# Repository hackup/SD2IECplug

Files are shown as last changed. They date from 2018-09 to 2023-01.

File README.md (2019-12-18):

SD2IEC Pluggable
================

* KiCAD project files for my take on a [SD2IEC](http://www.pitsch.de/stuff/mmc2iec/) compatible board.
* The schematics are heavily based on the [design by Shadowolf](https://www.forum64.de/index.php?thread/21242-sd2iec-hardware-1-0/).
* The [BOM export](SD2IECplug-BOM.csv) is included in the repository.
* There should probably be more documentation here, but while it is still missing you may find some additional information [on my blog](https://www.hackup.net/tag/sd2iec/).
* This is all work in progress with absolutely no guarantees. **USE AT YOUR OWN RISK!**

### Revision 2

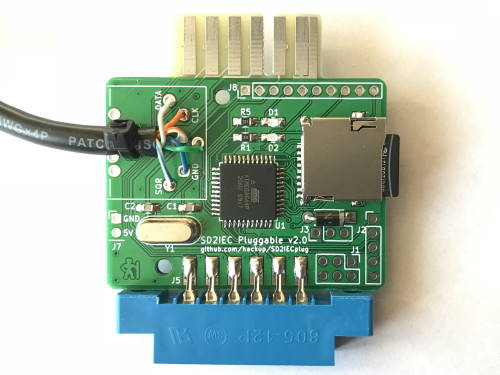
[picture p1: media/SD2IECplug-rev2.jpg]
SD2IECplug Rev.2


In revision 2, the PCB size has been reduced by more than 50% and TAPuino support has been ditched. It now features a Micro SD slot and a few other improvements. Note: In this revision, the numbering of the LEDs has been accidentally reversed. This has been fixed later on the master branch.

### Revision 1

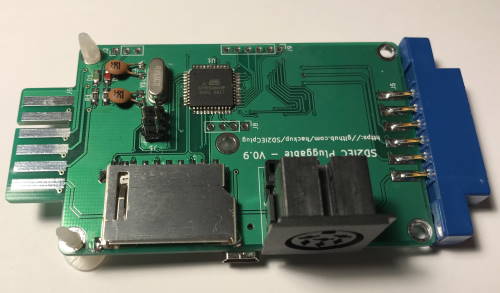
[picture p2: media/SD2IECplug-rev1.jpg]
SD2IECplug Rev.1


The first revision required a much larger PCB but featured a full-size SD slot and experimental support for TAPuino functionality. The latter was never tested though and probably wouldn't work.

If you don't intend to use the TAPuino functionality (and there isn't any firmware support for this yet) you can omit R16-R21 and the optocoupler U3. Also, the board can be power either through the USB or the tape port connector so you don't necessarily need to fit both.

## License


This work is licensed under a
[Creative Commons Attribution-NonCommercial-ShareAlike 4.0 International License](http://creativecommons.org/licenses/by-nc-sa/4.0/).

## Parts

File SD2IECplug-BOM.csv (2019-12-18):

Title | SD2IEC Pluggable
Revision | 2.1
Date | 2019-12-18
Generated | 18/12/2019 10:01:49
Company | www.hackup.net
Comment 1
Comment 2
Comment 3
Comment 4
Total Parts | 48
Total Unique Parts | 29
Ref | Qty | Value | Footprint | Datasheet | Manf | Manf#
C1 C2 | 2 | 56p | Capacitors_SMD:C_0805_HandSoldering
C3 C4 C5 | 3 | 10µ | Capacitors_Tantalum_SMD:CP_Tantalum_Case-S_EIA-3216-12_Hand
C6 | 1 | 100n | Capacitors_SMD:C_0805_HandSoldering
C7 | 1 | 100n | Capacitors_SMD:C_0805_HandSoldering | ~
D1 | 1 | red | LEDs:LED_0805_HandSoldering
D2 | 1 | green | LEDs:LED_0805_HandSoldering
D3 | 1 | 1N5817 | Diodes_THT:D_DO-41_SOD81_P7.62mm_Horizontal
J1 | 1 | ISP | Pin_Headers:Pin_Header_Straight_2x03_Pitch2.54mm
J2 | 1 | X6 | Pin_Headers:Pin_Header_Straight_1x05_Pitch2.54mm | ~
J3 | 1 | Aux | Pin_Headers:Pin_Header_Straight_1x03_Pitch2.54mm | ~
J4 | 1 | IEC | DIN-Connectors:DIN-6-Variable
J5 | 1 | C64-CassettePort | hackup:C64-Cassette-Port-Female
J6 | 1 | C64-CassettePort | hackup:C64-Cassette-Port-Male
J7 | 1 | Power | Pin_Headers:Pin_Header_Straight_1x02_Pitch2.54mm | ~
J8 | 1 | X3 | Pin_Headers:Pin_Header_Straight_1x10_Pitch2.54mm | ~
MH1 MH2 | 2 | ZipTie | DIN-Connectors:ZipTie_3.0mm | ~
MH3 MH4 | 2 | MountingHole | Mounting_Holes:MountingHole_2.7mm_M2.5 | ~
Q1 Q2 Q3 Q4 | 4 | BSS138 | TO_SOT_Packages_SMD:SOT-23_Handsoldering
R1 R5 | 2 | 330 | Resistors_SMD:R_0805_HandSoldering
R2 R6 R9 R12 | 4 | 18 | Resistors_SMD:R_0805_HandSoldering
R3 R7 R10 R13 | 4 | 10k | Resistors_SMD:R_0805_HandSoldering
R4 R8 R11 R14 | 4 | 22k | Resistors_SMD:R_0805_HandSoldering
R15 | 1 | 2.2R | Resistors_SMD:R_0805_HandSoldering
R16 | 1 | nB | Resistors_SMD:R_0805_HandSoldering | ~
SW1 SW2 | 2 | SW_Push | Buttons_Switches_SMD:SW_SPST_FSMSM
U1 | 1 | ATMEGA644-20AU | Housings_QFP:TQFP-44_10x10mm_Pitch0.8mm
U2 | 1 | AMS1117-3.3 | TO_SOT_Packages_SMD:SOT-223-3_TabPin2
XS1 | 1 | SD Connector | lib:Conn_uSDcard | _ | ebay | _
Y1 | 1 | 8MHz | Crystals:Crystal_HC49-4H_Vertical
BOM made with KICAD_BOM_WIZARD (https://github.com/HashDefineElectronics/KiCad_BOM_Wizard.git)
Generated 18/12/2019 10:01:49

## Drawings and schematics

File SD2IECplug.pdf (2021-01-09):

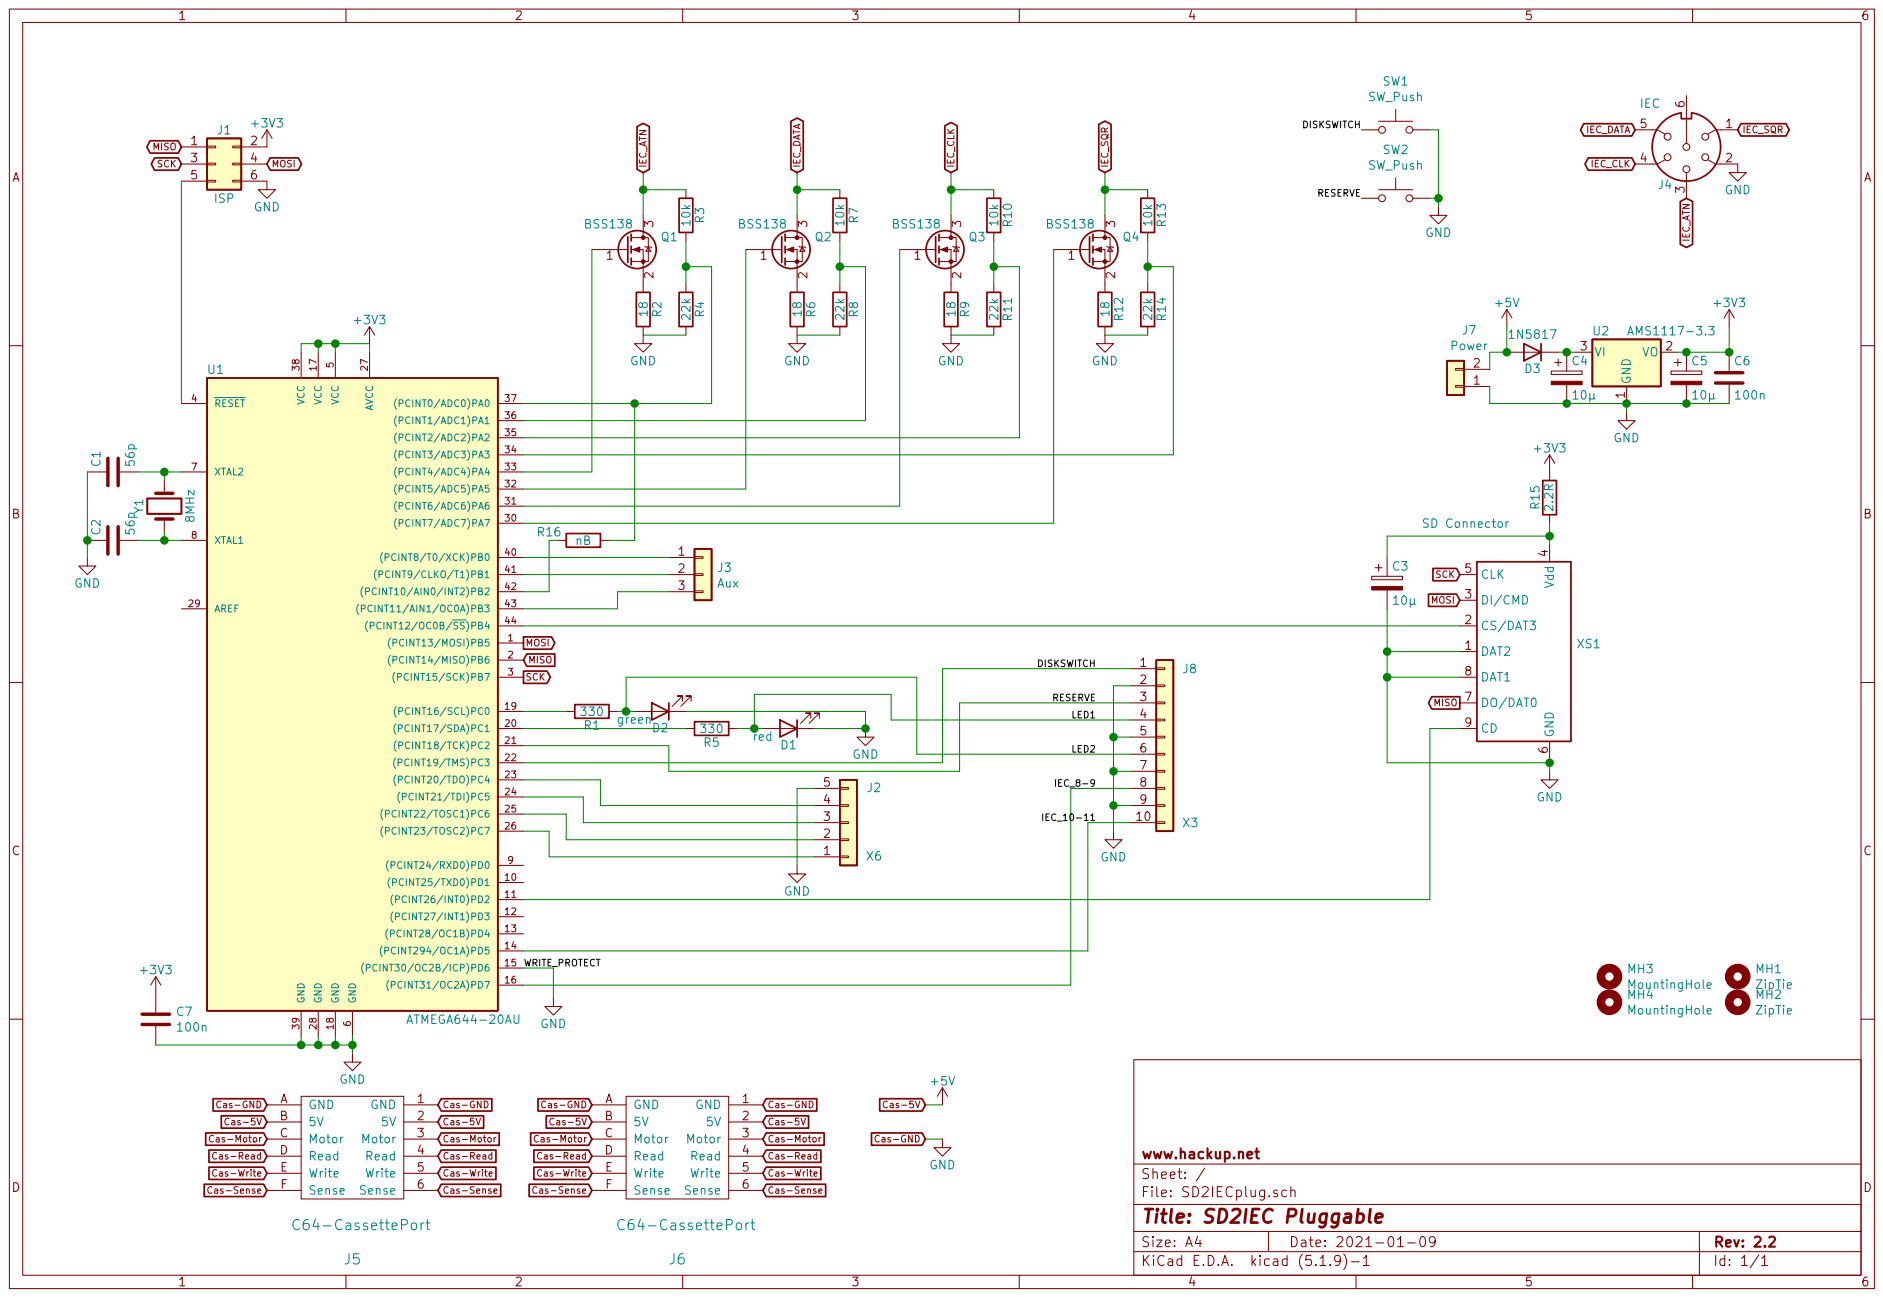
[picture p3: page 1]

6 DO/DAT0 7 DAT1 8 CD 9 XS1 SD Connector +5V GND GND MH1 ZipTie MH2 ZipTie GND

Cas-5V Cas-Motor MISO

LED2 | 5

File: SD2IECplug.sch Sheet: / www.hackup.net

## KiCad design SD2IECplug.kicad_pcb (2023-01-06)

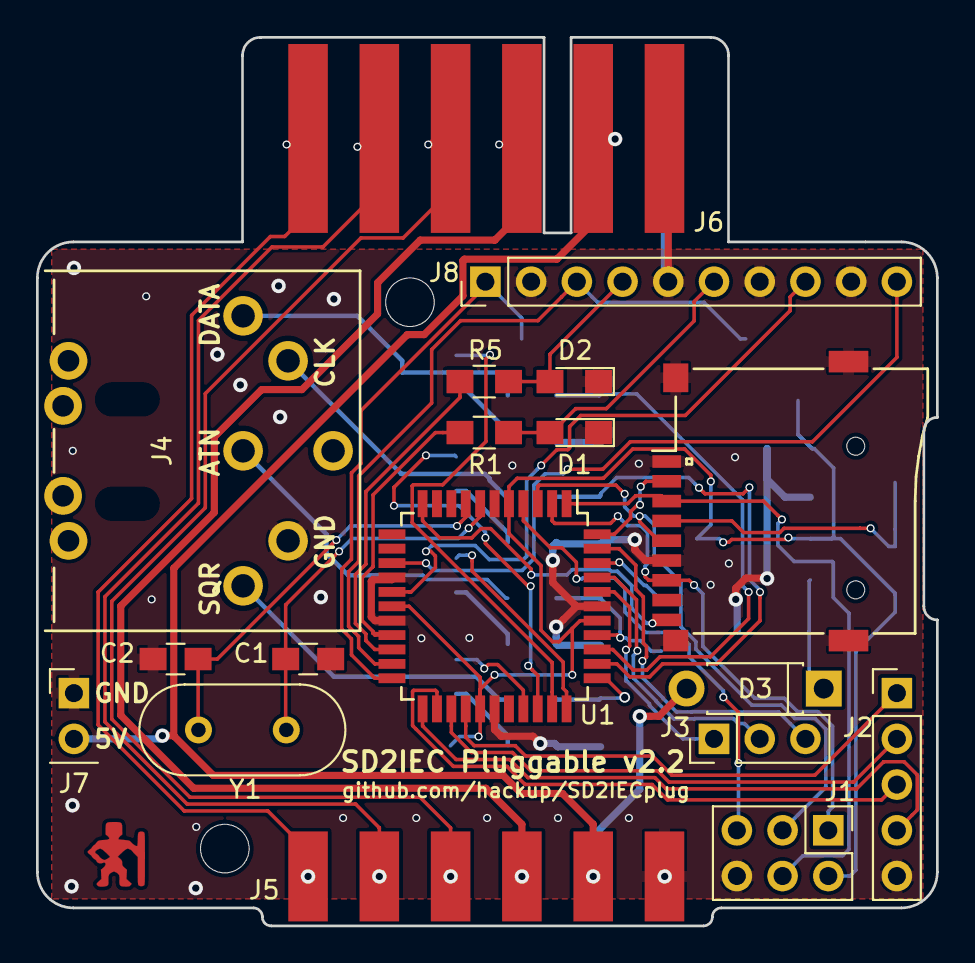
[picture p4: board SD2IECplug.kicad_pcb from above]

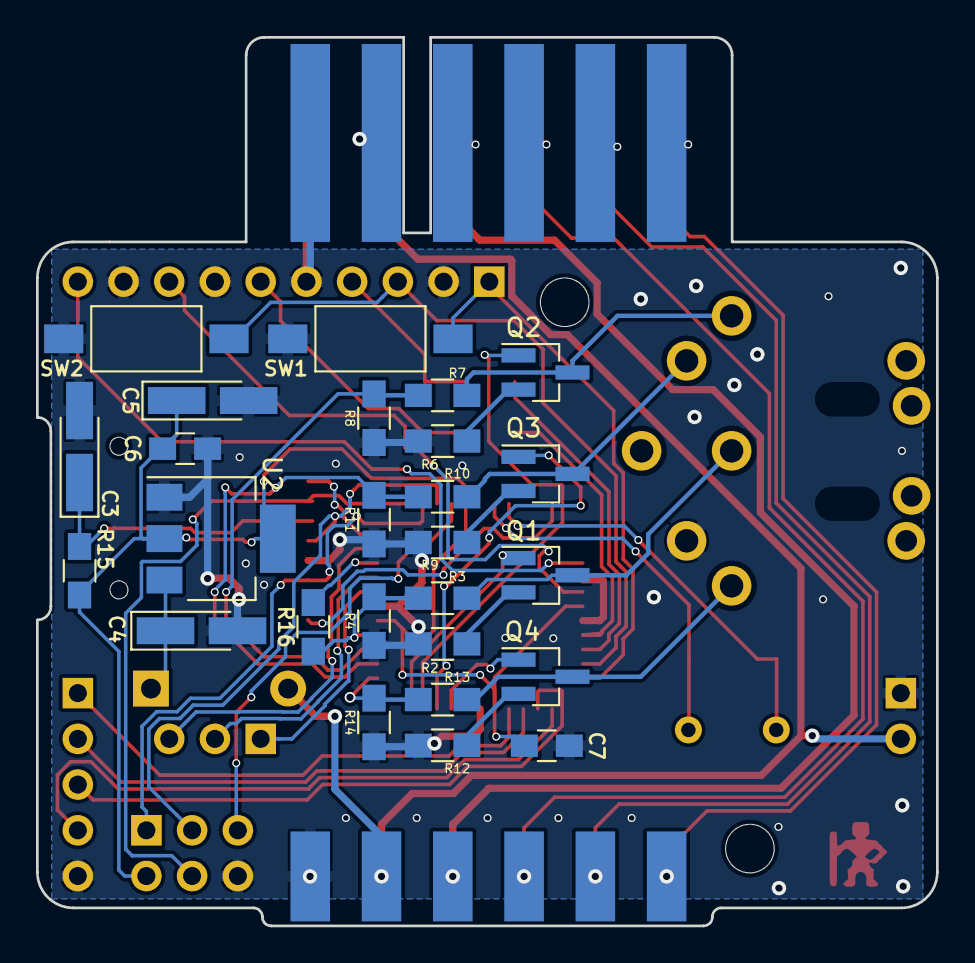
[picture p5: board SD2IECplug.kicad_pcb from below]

Board: 2 copper layers, 50.0 x 49.4 mm, 48 parts (26 on the bottom side), 49 nets.

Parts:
C1, C2: 56p; C_0805_HandSoldering
C3, C4, C5: 10µ; CP_Tantalum_Case-S_EIA-3216-12_Hand
C6, C7: 100n; C_0805_HandSoldering
D1: red; LED_0805_HandSoldering
D2: green; LED_0805_HandSoldering
D3: 1N5817; D_DO-41_SOD81_P7.62mm_Horizontal
J1: ISP; Pin_Header_Straight_2x03_Pitch2.54mm
J2: X6; Pin_Header_Straight_1x05_Pitch2.54mm
J3: Aux; Pin_Header_Straight_1x03_Pitch2.54mm
J4: IEC; DIN-6-Variable
J5: C64-CassettePort; C64-Cassette-Port-Female
J6: C64-CassettePort; C64-Cassette-Port-Male
J7: Power; Pin_Header_Straight_1x02_Pitch2.54mm
J8: X3; Pin_Header_Straight_1x10_Pitch2.54mm
MH1, MH2: ZipTie; ZipTie_3.0mm
MH3, MH4: MountingHole; MountingHole_2.7mm_M2.5
Q1, Q2, Q3, Q4: BSS138; SOT-23_Handsoldering
R1, R5: 330; R_0805_HandSoldering
R2, R6, R9, R12: 18; R_0805_HandSoldering
R3, R7, R10, R13: 10k; R_0805_HandSoldering
R4, R8, R11, R14: 22k; R_0805_HandSoldering
R15: 2.2R; R_0805_HandSoldering
R16: nB; R_0805_HandSoldering
SW1, SW2: SW_Push; SW_SPST_FSMSM
U1: ATMEGA644-20AU; TQFP-44_10x10mm_Pitch0.8mm
U2: AMS1117-3.3; SOT-223-3_TabPin2
XS1: SD Connector; Conn_uSDcard
Y1: 8MHz; Crystal_HC49-4H_Vertical

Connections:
+3V3: C5.1, C6.1, C7.1, J1.2, R15.2, U1.5, U1.17, U1.27, U1.38, U2.2
/DISKSWITCH: J8.1, SW1.1, U1.22
/IEC_8-9: J8.8, U1.16
/IEC_10-11: J8.10, U1.14
/LED1: D1.2, J8.4, R5.1
/LED2: D2.2, J8.6, R1.1
/RESERVE: J8.3, SW2.1, U1.21
Cas-5V: D3.2, J5.2, J5.B, J6.2, J6.B, J7.2
Cas-GND: C1.1, C2.1, C3.2, C4.2, C5.2, C6.2, C7.2, D1.1, D2.1, J1.6, J2.5, J4.2, J5.1, J5.A, J6.1, J6.A, J7.1, J8.2, J8.5, J8.7, J8.9, R2.2, R4.2, R6.2, R8.2, R9.2, R11.2, R12.2, R14.2, SW1.2, SW2.2, U1.6, U1.15, U1.18, U1.28, U1.39, U2.1, XS1.1, XS1.6, XS1.8
Cas-Motor: J5.3, J5.C, J6.3, J6.C
Cas-Read: J5.4, J5.D, J6.4, J6.D
Cas-Sense: J5.6, J5.F, J6.6, J6.F
Cas-Write: J5.5, J5.E, J6.5, J6.E
IEC_ATN: J4.3, Q1.3, R3.1
IEC_CLK: J4.4, Q3.3, R10.1
IEC_DATA: J4.5, Q2.3, R7.1
IEC_SQR: J4.1, Q4.3, R13.1
MISO: J1.1, U1.2, XS1.7
MOSI: J1.4, U1.1, XS1.3
unnamed: C1.2, U1.7, Y1.2
unnamed: C2.2, U1.8, Y1.1
unnamed: C3.1, R15.1, XS1.4
unnamed: C4.1, D3.1, U2.3
unnamed: J1.5, U1.4
unnamed: J2.1, U1.26
unnamed: J2.2, U1.25
unnamed: J2.3, U1.24
unnamed: J2.4, U1.23
unnamed: J3.1, U1.40
unnamed: J3.2, U1.41
unnamed: J3.3, U1.43
unnamed: Q1.1, U1.33
unnamed: Q1.2, R2.1
unnamed: Q2.1, U1.32
unnamed: Q2.2, R6.1
unnamed: Q3.1, U1.31
unnamed: Q3.2, R9.1
unnamed: Q4.1, U1.30
unnamed: Q4.2, R12.1
unnamed: R1.2, U1.19
unnamed: R5.2, U1.20
unnamed: R7.2, R8.1, U1.36
unnamed: R10.2, R11.1, U1.35
unnamed: R13.2, R14.1, U1.34
unnamed: R3.2, R4.1, R16.1, U1.37
unnamed: R16.2, U1.42
unnamed: U1.11, XS1.9
unnamed: U1.44, XS1.2
SCK: J1.3, U1.3, XS1.5

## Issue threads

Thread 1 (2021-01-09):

Capacitor in wrong place?

SukkoPera, 2021-01-09:
Hi, thanks for sharing this nice project. I had a look at it and I think that the way C3 is connected doesn't make much sense, could you please check?

On the same topic, may I ask why you deemed it necessary to put a current-limiting resistor on the SD power rail (R15)?

Thanks for your time :).

hackup, 2021-01-09:
Thanks for your feedback! I just had a quick look and it really seems that C3 is connected the wrong way in v2.0. It was still correct in the previous release v0.9. I will look closer and supply and updated version.

As noted in the project description, most of the schematic is taken from Shadowolf's design. If I recall correctly, there are some SD cards that will draw too much power on startup and R15 is meant to prevent this. I'll try to find the source for this and get back to you if I do.

hackup, 2021-01-09:
I think I found the post regarding the current-limiting resistor:
https://www.forum64.de/index.php?thread/53167-sd2iec-v1-2-shadowolf/&postID=746897#post746897

R15 here is the same as R20 in the original schematic. It seems that there are some cards which cause such a high inrush current that the MCU resets when the card is inserted while the device is powered on.

SukkoPera, 2021-01-10:
Thanks a lot! Unfortunately I had already removed it from my fork and I'm too lazy to add it back. Never mind, I am not too interested in changing the card while the device is powered on.

Closed 2021-01-09.

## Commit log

2017-11-24 Inital commit.
    [SD2IECplug.kicad_pcb, SD2IECplug.sch]
2017-11-24 Fill areas.
    [SD2IECplug.kicad_pcb]
2017-11-24 Keep Makefile only in gerber dir.
2017-11-24 Added optional I2C connector.
    [SD2IECplug.kicad_pcb, SD2IECplug.sch]
2017-11-24 Removed push button, added switch header.
    [SD2IECplug.kicad_pcb, SD2IECplug.sch]
2017-11-24 Added another mounting hole.
    [SD2IECplug.kicad_pcb]
2017-11-24 Forgotten changes.
    [SD2IECplug.sch]
2017-12-06 Bug fix: Mini USB GND actually seems to be on pin 5.
    [SD2IECplug.kicad_pcb, SD2IECplug.sch]
2017-12-10 Changed diode D3 footprint.
    [SD2IECplug.kicad_pcb, SD2IECplug.sch]
2017-12-25 Upgraded project files.
    [SD2IECplug.kicad_pcb, SD2IECplug.sch]
2018-01-17 Added BOM export and notes.
    [SD2IECplug-BOM.csv]
2018-09-10 First steps.
    [SD2IECplug.kicad_pcb, SD2IECplug.sch]
2018-09-10 First routing.
    [SD2IECplug.kicad_pcb, SD2IECplug.sch]
2018-09-11 Indent PCB for SD card.
    [SD2IECplug.kicad_pcb]
2018-09-11 Moced SD connector.
    [SD2IECplug.kicad_pcb]
2018-09-11 Ziptie holes and silk screen cleanup.
    [SD2IECplug.kicad_pcb, SD2IECplug.sch]
2018-09-12 Improved routing.
    [SD2IECplug.kicad_pcb]
2018-09-12 Added missing resistor and yet another breakout header.
    [SD2IECplug.kicad_pcb, SD2IECplug.sch]
2018-09-12 Aligned connectors to grid.
    [SD2IECplug.kicad_pcb]
2018-09-12 Added mounting hole.
    [SD2IECplug.kicad_pcb, SD2IECplug.sch]
2018-09-12 Increased motor line track width.
    [SD2IECplug.kicad_pcb]
2018-09-12 Aligned external power connector.
    [SD2IECplug.kicad_pcb, SD2IECplug.sch]
2018-09-12 Added decoupling cap.
    [SD2IECplug.kicad_pcb, SD2IECplug.sch]
2018-09-12 Added push buttons.
    [SD2IECplug.kicad_pcb, SD2IECplug.sch]
2018-09-12 Old gerber files.
2018-09-12 Fixed board edge.
    [SD2IECplug.kicad_pcb]
2018-09-13 Reduced silk screen outline.
    [SD2IECplug.kicad_pcb]
2018-09-13 Round SD card recess.
    [SD2IECplug.kicad_pcb]
2018-09-14 Ordered prototype batch of 4x4 panels.
    [SD2IECplug-panel.kicad_pcb]
2018-10-08 Corrected ground plane.
    [SD2IECplug.kicad_pcb]
2018-10-08 Moved data lines further away from drill holes.
    [SD2IECplug.kicad_pcb]
2018-10-08 Revision increment.
    [SD2IECplug.kicad_pcb]
2018-10-08 Improved ziptie holes.
    [SD2IECplug.kicad_pcb, SD2IECplug.sch]
2018-10-08 IRLML2803 -> BSS138
    [SD2IECplug.kicad_pcb, SD2IECplug.sch]
2018-10-14 Corrected LED numbering.
    [SD2IECplug.kicad_pcb, SD2IECplug.sch]
2018-10-15 Updated BOM.
    [SD2IECplug-BOM.csv]
2018-10-31 Moved connector pads to the edge.
    [SD2IECplug.kicad_pcb]
2018-10-31 Extrude connector pads.
    [SD2IECplug.kicad_pcb]
2018-11-12 Added schematics export.
2019-12-18 Fixed symbol library references.
    [SD2IECplug.kicad_pcb, SD2IECplug.sch]
2021-01-09 Placement of C3 got messed up between v0.9 and v2.0, fixes #1.
    [SD2IECplug.kicad_pcb, SD2IECplug.sch]
2023-01-06 Updated to KiCAD 6, fixed a few warnings.
    [SD2IECplug.kicad_pcb, SD2IECplug.kicad_sch]
2023-01-06 Created gerber files for latest version.
    [SD2IECplug.kicad_pcb]
